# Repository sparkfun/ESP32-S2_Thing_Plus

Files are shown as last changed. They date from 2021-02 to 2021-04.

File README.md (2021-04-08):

SparkFun ESP32-S2 Thing Plus
========================================

SparkFun ESP32-S2 Thing Plus (https://www.sparkfun.com/products/17743)

[*SparkFun ESP32-S2 Thing Plus (WRL-17381)*](https://www.sparkfun.com/products/17743)

The [SparkFun ESP32-S2 Thing Plus](https://www.sparkfun.com/products/17743) is a comprehensive development platform for [Espressif's ESP32](https://espressif.com/en/products/hardware/esp32/overview). This board has the ESP32-S2-WROOM (4MB) version of the module. The new ESP32-S2 module addresses the [security flaws](https://www.espressif.com/en/news/ESP32_FIA_Analysis) in the original ESP32. While the ESP32-S2 does include improved security features, it lacks the Bluetooth capabilities of the original ESP32 module. The ESP32-S2 Thing Plus includes a Qwiic adapter, LiPo battery JST connector, and 21 I/O pins.

Repository Contents
-------------------

* **/Hardware** - Eagle design files (.brd, .sch)
* **/Hardware/Production** - Production panel files (gerbers, .brd)

Documentation
--------------
* **[Hookup Guide](https://learn.sparkfun.com/tutorials/1660)** - Basic hookup guide for the ESP32-S2 Thing Plus.
* **[SparkFun Graphical Datasheets](https://github.com/sparkfun/Graphical_Datasheets)** -Graphical Datasheets for various SparkFun products.

Product Versions
----------------
* [WRL-17743](https://www.sparkfun.com/products/17743)- v1.0, Initial Release

License Information
-------------------

This product is _**open source**_! 

Please review the LICENSE.md file for license information. 

If you have any questions or concerns on licensing, please contact technical support on our [SparkFun forums](https://forum.sparkfun.com/viewforum.php?f=152).

Distributed as-is; no warranty is given.

- Your friends at SparkFun.

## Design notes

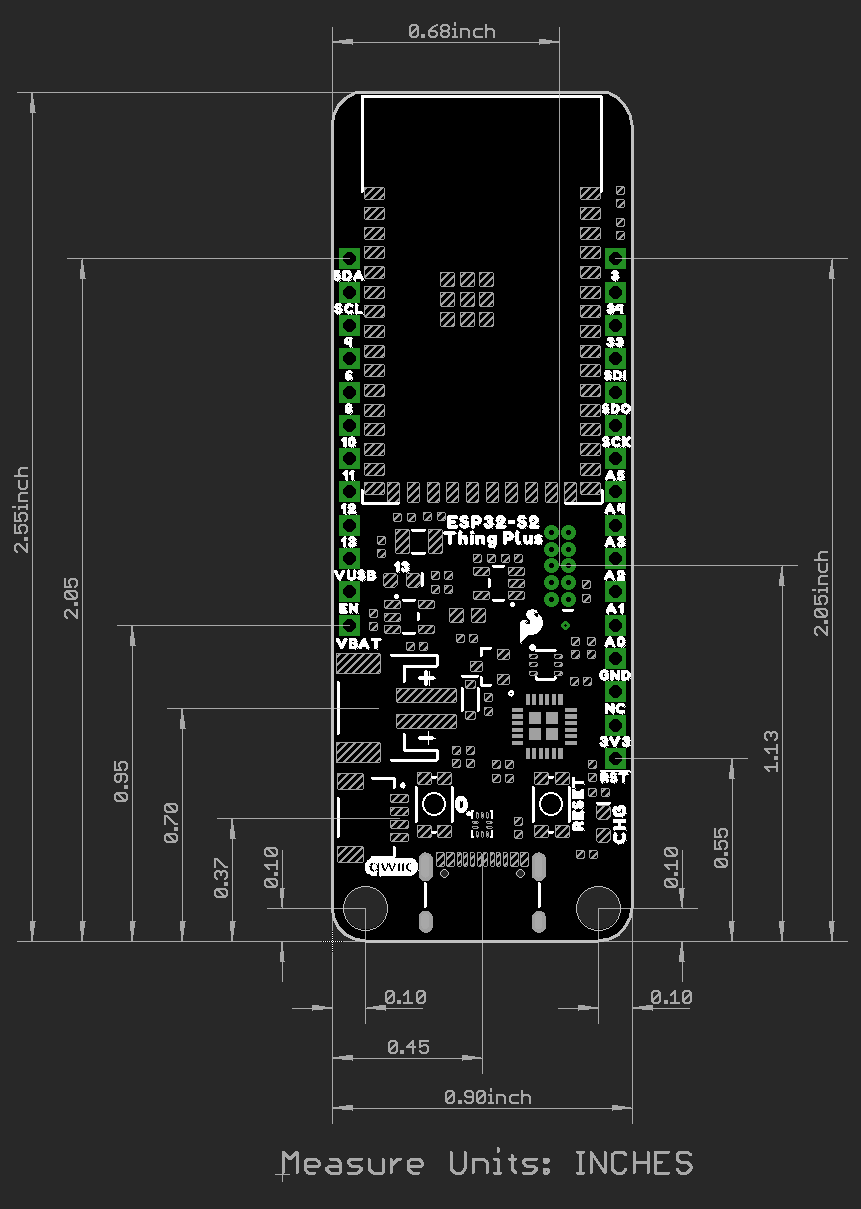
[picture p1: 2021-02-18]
Documents/ESP32-S2_Thing_Plus_DIMENSIONS.png

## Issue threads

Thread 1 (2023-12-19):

Feature Request: Battery charge status

santaimpersonator, 2023-12-19:
From customer feedback:

> There is only one thing I miss that I think you should consider changing for next iteration. A way to read charging status from the controller. To get this i soldered an aditional wire from the charging led to one of the pins. It does not even have to be there all the time, it could be a pad to solder closed and sacrifice a pin or something like this.

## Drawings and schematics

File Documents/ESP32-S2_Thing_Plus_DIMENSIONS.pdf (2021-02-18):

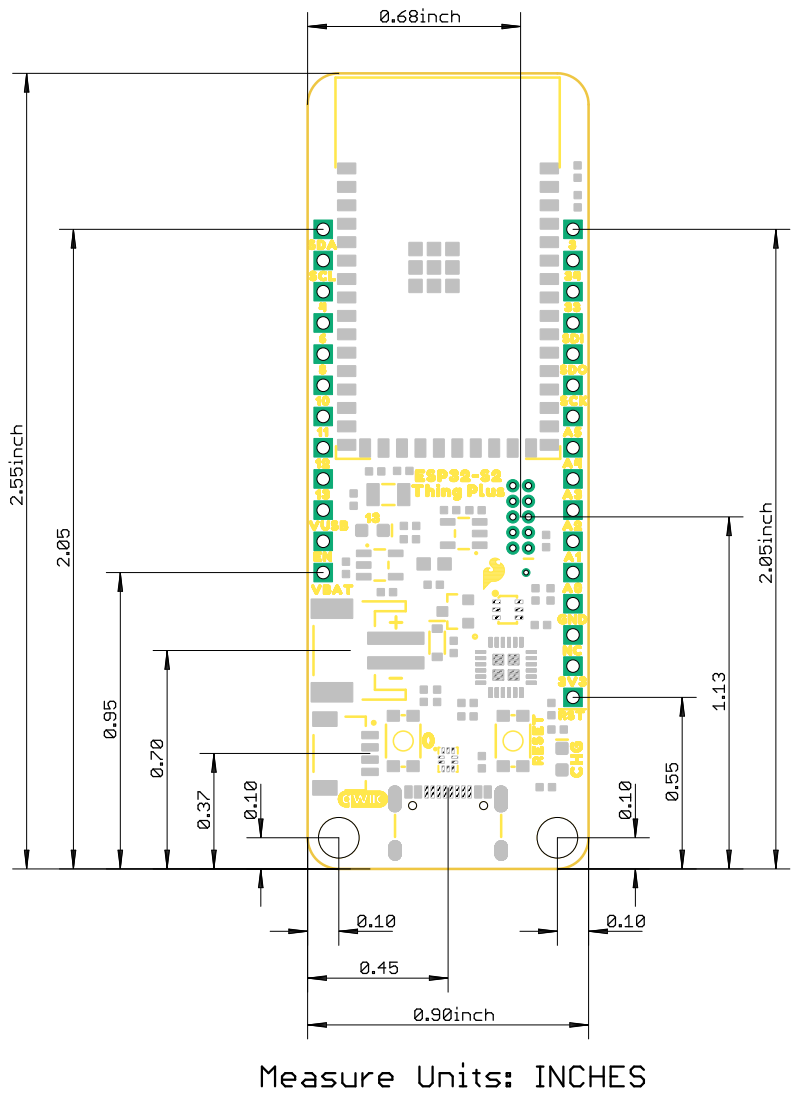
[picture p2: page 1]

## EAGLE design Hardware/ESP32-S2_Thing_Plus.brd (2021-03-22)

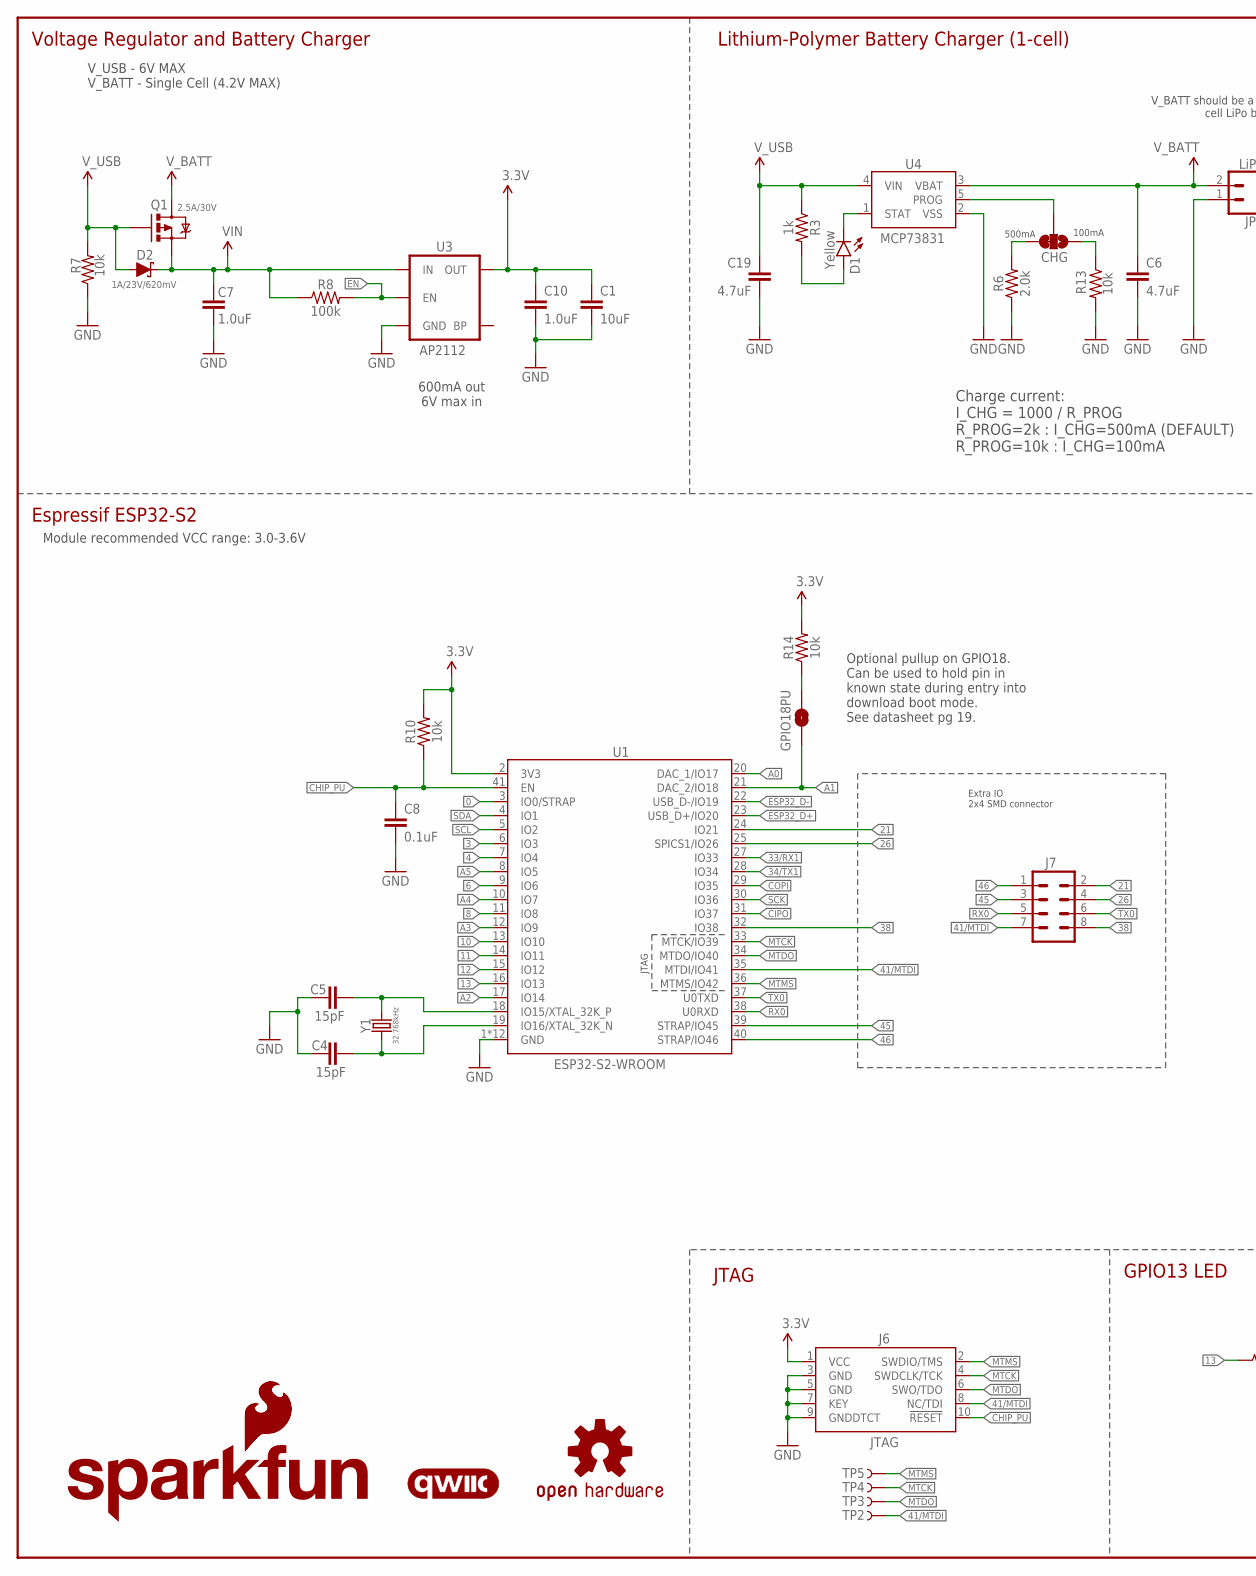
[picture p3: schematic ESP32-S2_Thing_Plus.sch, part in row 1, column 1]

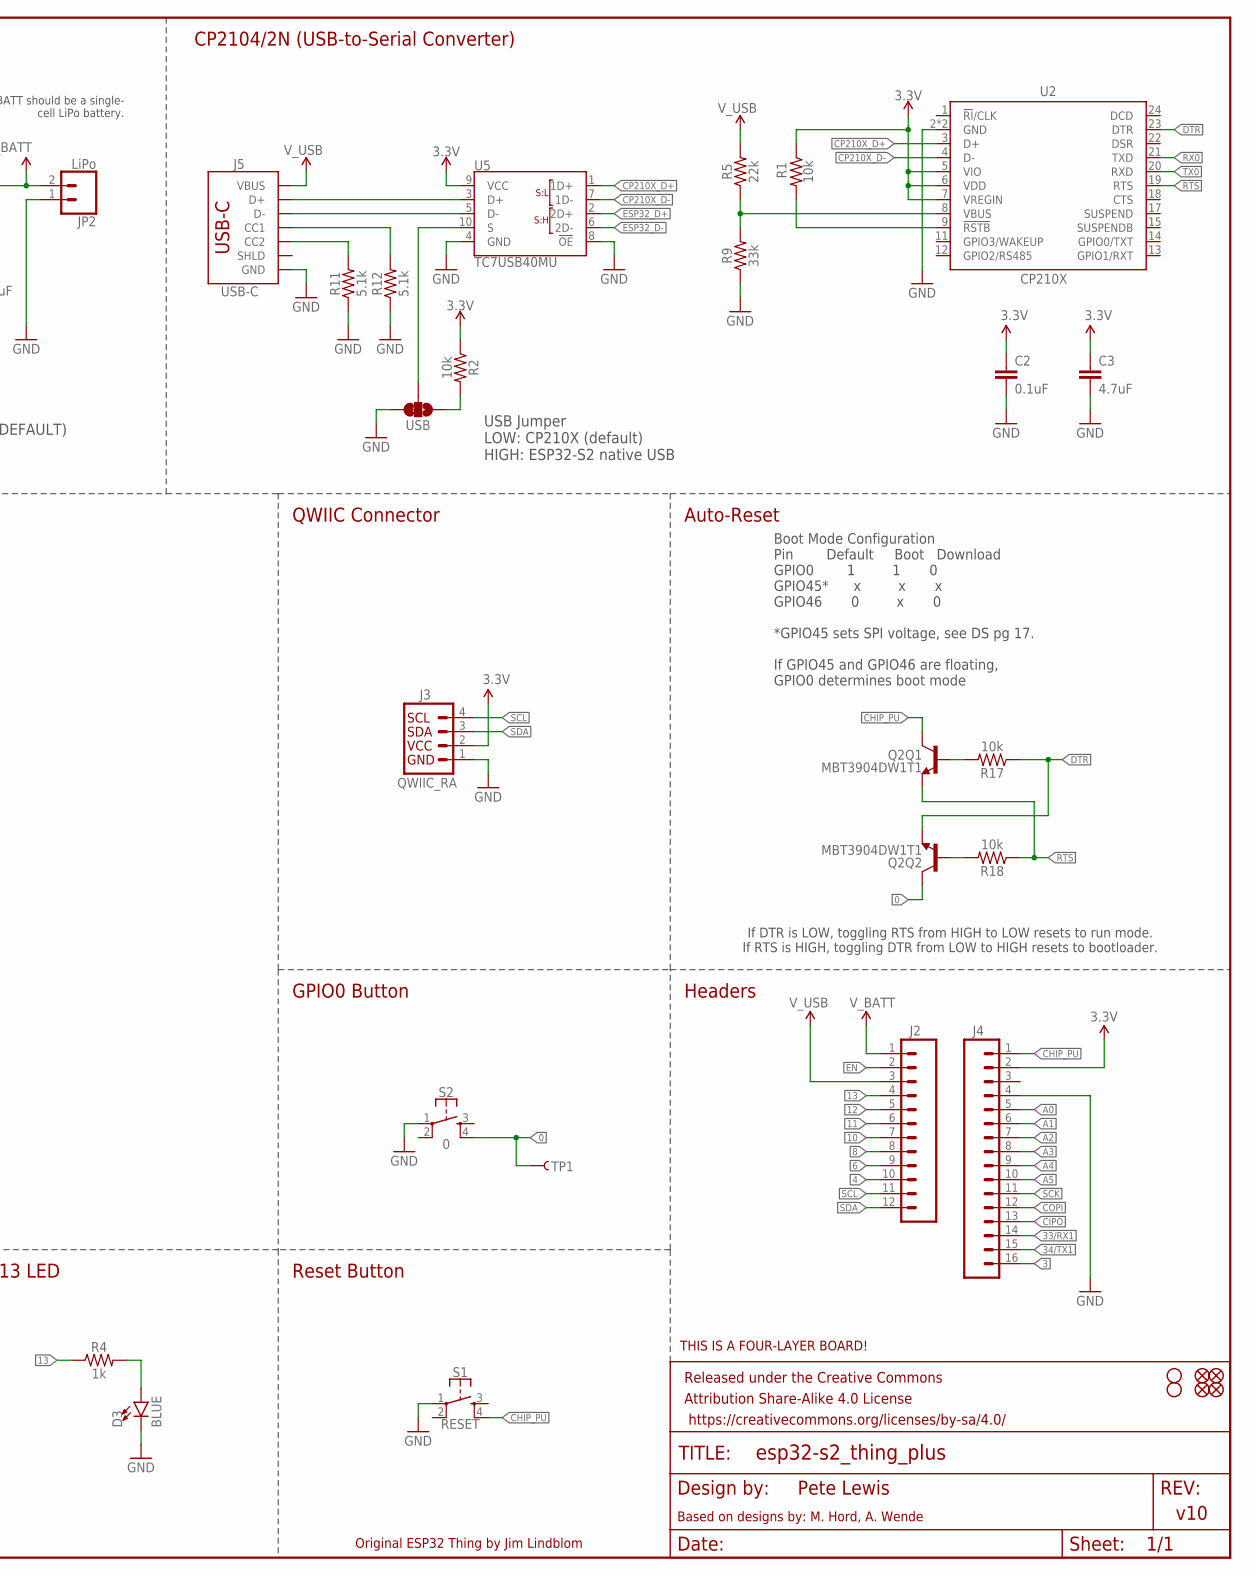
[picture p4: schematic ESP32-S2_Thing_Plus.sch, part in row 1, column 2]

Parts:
C1: 10uF; 0402-TIGHT
C2, C8: 0.1uF; 0402-TIGHT
C3, C6, C19: 4.7uF; 0402-TIGHT
C4, C5: 15pF; 0402-TIGHT
C7, C10: 1.0uF; 0402-TIGHT
CHG: JUMPER-SMT_3_1-NC_TRACE_SILK; SMT-JUMPER_3_1-NC_TRACE_SILK
D1: Yellow; LED-0603
D2: 1A/23V/620mV; SOD-323
D3: BLUE; LED-0603
FD1, FD2, FD3, FD4: FIDUCIALUFIDUCIAL; FIDUCIAL-MICRO
FRAME1: FRAME-LEDGER; CREATIVE_COMMONS
GPIO18PU: JUMPER-SMT_2_NO_SILK; SMT-JUMPER_2_NO_SILK
H1, H2: STAND-OFF
J2: CONN_12SM_SQ_NO_SILK; 1X12_SM_SQ_NOSILK
J3: QWIIC_RA; JST04_1MM_RA
J4: CONN_161X16_SM_SQ_NOSILK; 1X16_SM_SQ_NOSILK
J5: USB-C; USB-C-16P-4LAYER-ISOLATED
J6: JTAG; 2X5-PTH-1.27MM-NO_SILK
J7: CONN_04X2_SMT_NO_POSTS_NS; 2X4_SMT_NO_POSTS_NS
JP2: LiPo; JST-2-SMD
LOGO1: SFE_LOGO_FLAME.1_INCH; SFE_LOGO_FLAME_.1
LOGO2: OSHW-LOGOMINI; OSHW-LOGO-MINI
LOGO3: SFE_LOGO_NAME_FLAME.1_INCH; SFE_LOGO_NAME_FLAME_.1
LOGO4: FOUR_LAYER_WARNING
LOGO6: QWIIC_LOGO_4MM; QWIIC_4MM
Q1: 2.5A/30V; SOT23-3@1
Q2: MBT3904DW1T1; SC70-6
R1, R2, R7, R10, R13, R14, R17, R18: 10k; 0402-TIGHT
R3, R4: 1k; 0402-TIGHT
R5: 22k; 0402-TIGHT
R6: 2.0k; 0603
R8: 100k; 0402-TIGHT
R9: 33k; 0402-TIGHT
R11, R12: 5.1k; 0402-TIGHT
S1: RESET; TACTILE_SWITCH_SMD_4.6X2.8MM
S2: 0; TACTILE_SWITCH_SMD_4.6X2.8MM
TP1: TEST-POINTTP_15TH_THRU; TP_15TH
TP2, TP3, TP4, TP5: TEST-POINT3X4; PAD.03X.04
U1: ESP32-S2-WROOM
U2: CP210X; QFN24
U3: AP2112; SOT23-5
U4: MCP73831; SOT23-5
U5: TC7USB40MU; UQFN10
USB: JUMPER-SMT_3_1-NC_TRACE_SILK; SMT-JUMPER_3_1-NC_TRACE_SILK
Y1: 32.768kHz; CRYSTAL-SMD-3.2X1.5MM

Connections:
0: Q2.6 (C), S2.4, TP1.P$1, U1.3 (IO0/STRAP)
3: J4.16, U1.6 (IO3)
3.3V: C1.1, C2.1, C3.1, C10.1, J3.2, J4.2, J6.1 (VCC), R1.1, R2.1, R10.2, R14.2, U1.2 (3V3), U2.5 (VIO), U2.6 (VDD), U2.7 (VREGIN), U3.5 (OUT), U5.9 (VCC)
4: J2.10, U1.7 (IO4)
6: J2.9, U1.9 (IO6)
8: J2.8, U1.11 (IO8)
10: J2.7, U1.13 (IO10)
11: J2.6, U1.14 (IO11)
12: J2.5, U1.15 (IO12)
13: J2.4, R4.1, U1.16 (IO13)
21: J7.2, U1.24 (IO21)
26: J7.4, U1.25 (SPICS1/IO26)
33/RX1: J4.14, U1.27 (IO33)
34/TX1: J4.15, U1.28 (IO34)
38: J7.8, U1.32 (IO38)
41/MTDI: J6.8 (NC/TDI), J7.7, TP2.P$1, U1.35 (MTDI/IO41)
45: J7.3, U1.39 (STRAP/IO45)
46: J7.1, U1.40 (STRAP/IO46)
A0: J4.5, U1.20 (DAC_1/IO17)
A1: GPIO18PU.1, J4.6, U1.21 (DAC_2/IO18)
A2: J4.7, U1.17 (IO14)
A3: J4.8, U1.12 (IO9)
A4: J4.9, U1.10 (IO7)
A5: J4.10, U1.8 (IO5)
CC1: J5.A5 (CC1), R12.2
CC2: J5.B5 (CC2), R11.2
CHG: D1.C, U4.1 (STAT)
CHIP_PU: C8.1, J4.1, J6.10 (!RESET), Q2.3 (C), R10.1, S1.4, U1.41 (EN)
CIPO: J4.13, U1.31 (IO37)
COPI: J4.12, U1.29 (IO35)
CP210X_D+: U2.3 (D+), U5.1 (1D+)
CP210X_D-: U2.4 (D-), U5.7 (1D-)
DTR: Q2.1 (E), R17.1, U2.23 (DTR)
EN: J2.2, R8.2, U3.3 (EN)
ESP32_D+: U1.23 (USB_D+/IO20), U5.2 (2D+)
ESP32_D-: U1.22 (USB_D-/IO19), U5.6 (2D-)
GND: C1.2, C2.2, C3.2, C4.1, C5.1, C6.2, C7.2, C8.2, C10.2, C19.2, D3.C, J3.1, J4.4, J5.GND, J5.GND2 (GND), J6.3 (GND), J6.5 (GND), J6.7 (KEY), J6.9 (GNDDTCT), JP2.1 (2), R6.1, R7.1, R9.1, R11.1, R12.1, R13.2, S1.1, S2.1, U1.1 (GND), U1.26 (GND), U1.42 (GND), U1.GNDEP0 (GND), U1.GNDEP1 (GND), U1.GNDEP2 (GND), U1.GNDEP3 (GND), U1.GNDEP4 (GND), U1.GNDEP5 (GND), U1.GNDEP6 (GND), U1.GNDEP7 (GND), U1.GNDEP8 (GND), U2.2 (GND), U2.PAD (GND), U3.2 (GND), U4.2 (VSS), U5.4 (GND), U5.8 (!OE!), USB.3
MTCK: J6.4 (SWDCLK/TCK), TP4.P$1, U1.33 (MTCK/IO39)
MTDO: J6.6 (SWO/TDO), TP3.P$1, U1.34 (MTDO/IO40)
MTMS: J6.2 (SWDIO/TMS), TP5.P$1, U1.36 (MTMS/IO42)
unnamed: R1.2, U2.9 (!RSTB)
unnamed: D3.A, R4.2
unnamed: J5.A6 (D+), J5.B6 (D+), U5.3 (D+)
unnamed: R5.1, R9.2, U2.8 (VBUS)
unnamed: J5.A7 (D-), J5.B7 (D-), U5.5 (D-)
unnamed: R2.2, USB.1
unnamed: C5.2, U1.18 (IO15/XTAL_32K_P), Y1.P$2 (2)
unnamed: C4.2, U1.19 (IO16/XTAL_32K_N), Y1.P$1 (1)
unnamed: CHG.2, U4.5 (PROG)
unnamed: Q2.5 (B), R17.2
unnamed: CHG.1, R13.1
unnamed: Q2.2 (B), R18.2
unnamed: CHG.3, R6.2
unnamed: GPIO18PU.2, R14.1
unnamed: D1.A, R3.2
RTS: Q2.4 (E), R18.1, U2.19 (RTS)
RX0: J7.5, U1.38 (U0RXD), U2.21 (TXD)
SCK: J4.11, U1.30 (IO36)
SCL: J2.11, J3.4, U1.5 (IO2)
SDA: J2.12, J3.3, U1.4 (IO1)
TX0: J7.6, U1.37 (U0TXD), U2.20 (RXD)
USB_SEL: U5.10 (S), USB.2
VIN: C7.1, D2.C, Q1.2 (S), R8.1, U3.1 (IN)
V_BATT: C6.1, J2.1, JP2.2 (1), Q1.3 (D), U4.3 (VBAT)
V_USB: C19.1, D2.A, J2.3, J5.VBUS1 (VBUS), J5.VBUS2 (VBUS), Q1.1 (G), R3.1, R5.2, R7.2, U4.4 (VIN)

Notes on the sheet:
Boot Mode Configuration Pin Default Boot Download GPIO0 1 1 0 GPIO45* x x x GPIO46 0 x 0 *GPIO45 sets SPI voltage, see DS pg 17. If GPIO45 and GPIO46 are floating, GPIO0 determines boot mode
CP2104/2N (USB-to-Serial Converter)
V_BATT should be a single- cell LiPo battery.
Charge current: I_CHG = 1000 / R_PROG R_PROG=2k : I_CHG=500mA (DEFAULT) R_PROG=10k : I_CHG=100mA
Voltage Regulator and Battery Charger
Lithium-Polymer Battery Charger (1-cell)
600mA out 6V max in
Auto-Reset
Espressif ESP32-S2
Reset Button
Headers
v10
Original ESP32 Thing by Jim Lindblom
If DTR is LOW, toggling RTS from HIGH to LOW resets to run mode. If RTS is HIGH, toggling DTR from LOW to HIGH resets to bootloader.
QWIIC Connector
Pete Lewis
GPIO13 LED
GPIO0 Button
Based on designs by: M. Hord, A. Wende
V_USB - 6V MAX V_BATT - Single Cell (4.2V MAX)
100mA
500mA
Extra IO 2x4 SMD connector
JTAG
Module recommended VCC range: 3.0-3.6V
USB Jumper LOW: CP210X (default) HIGH: ESP32-S2 native USB
Optional pullup on GPIO18. Can be used to hold pin in known state during entry into download boot mode. See datasheet pg 19.

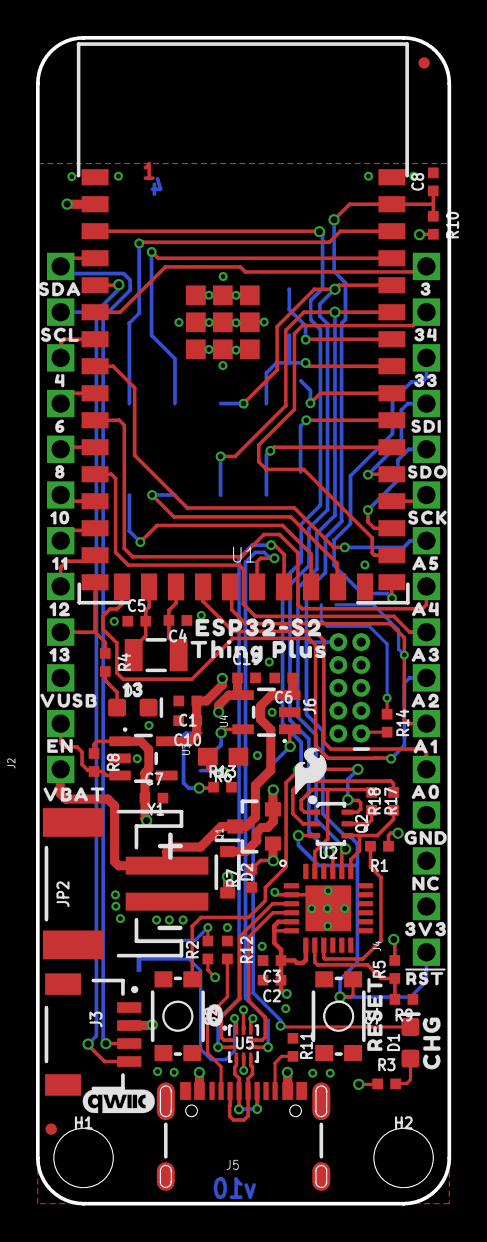
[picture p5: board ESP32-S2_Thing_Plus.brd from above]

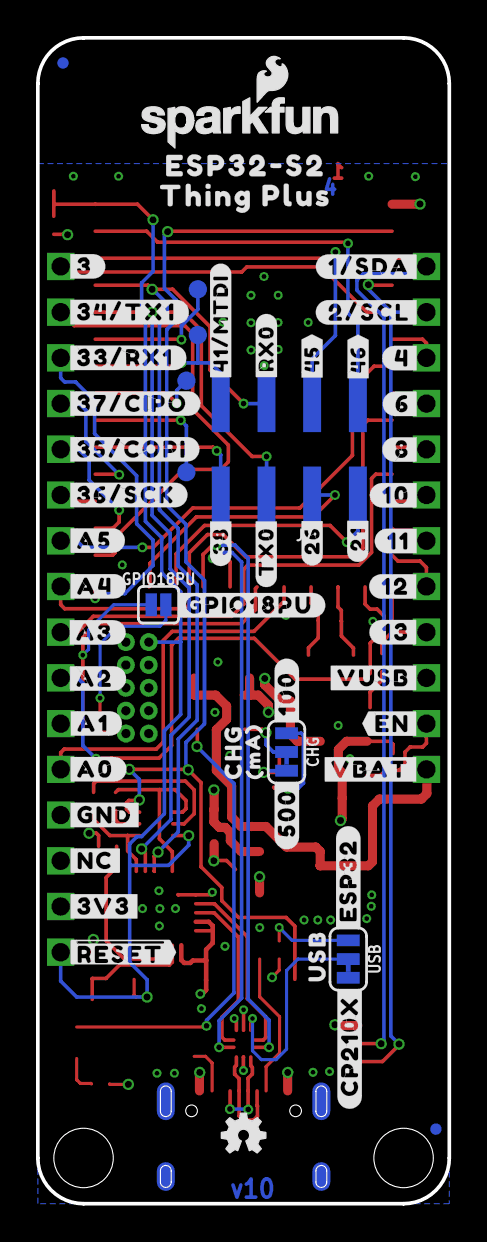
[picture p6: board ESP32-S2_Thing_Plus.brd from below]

Board: 4 copper layers, 22.9 x 64.8 mm, 147 parts (58 on the bottom side), 65 nets.

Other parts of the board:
U$1: #CP210X#0
U$2: SDI0
U$3, U$78: CHG0
U$4: #500#0
U$5: ESP32#S20
U$6: SDO0
U$7: #RST#0
U$8: #46#0
U$9: #ESP32#0
U$10: #45#0
U$11: MA0
U$12: #A5#0
U$14: USB0
U$15: 110
U$16: #GPIO18PU#0
U$17: 100
U$18: 80
U$19: #A4#0
U$20: 60
U$21: #A2#0
U$22: #A3#0
U$23: 40
U$24: 330
U$25: SDA0
U$26: SCL0
U$28: #A0#0
U$29: 340
U$30: 30
U$31: #36#SCK#0
U$32: #GND#0
U$33: #35#COPI#0
U$34: #37#CIPO#0
U$35: #33#RX1#0
U$36: #34#TX1#0
U$37: #3#0
U$38: #41#MTDI#0
U$39: #12#0
U$40: #13#0
U$41: #VUSB#0
U$42: #VBAT#0
U$43: #EN#0
U$44: #NC#0
U$45: #3V3#0
U$46: ##RESET##0
U$47: #11#0
U$48: #6#0
U$49: #8#0
U$50: #10#0
U$51: #4#0
U$52: #1#SDA#0
U$53: #2#SCL#0
U$54: #21#0
U$55: #26#0
U$56: #TX0#0
U$57: #38#0
U$58: #RX0#0
U$59: ORDERING_INSTRUCTIONS
U$60: #100#0
U$61: THING_PLUS0
U$62: THING_PLUS_0
U$63: ESP32#S2_0
U$64: #A1#0
U$72: 120
U$73, U$74: 130
U$75: VUSB0
U$76: EN0
U$77: VBAT0
U$79: RESET0
U$81: 3V30
U$82: NC0
U$83: GND0
U$84: A00
U$85: A10
U$86: A20
U$87: A30
U$88: A40
U$89: A50
U$90: SCK0
U$96: 00

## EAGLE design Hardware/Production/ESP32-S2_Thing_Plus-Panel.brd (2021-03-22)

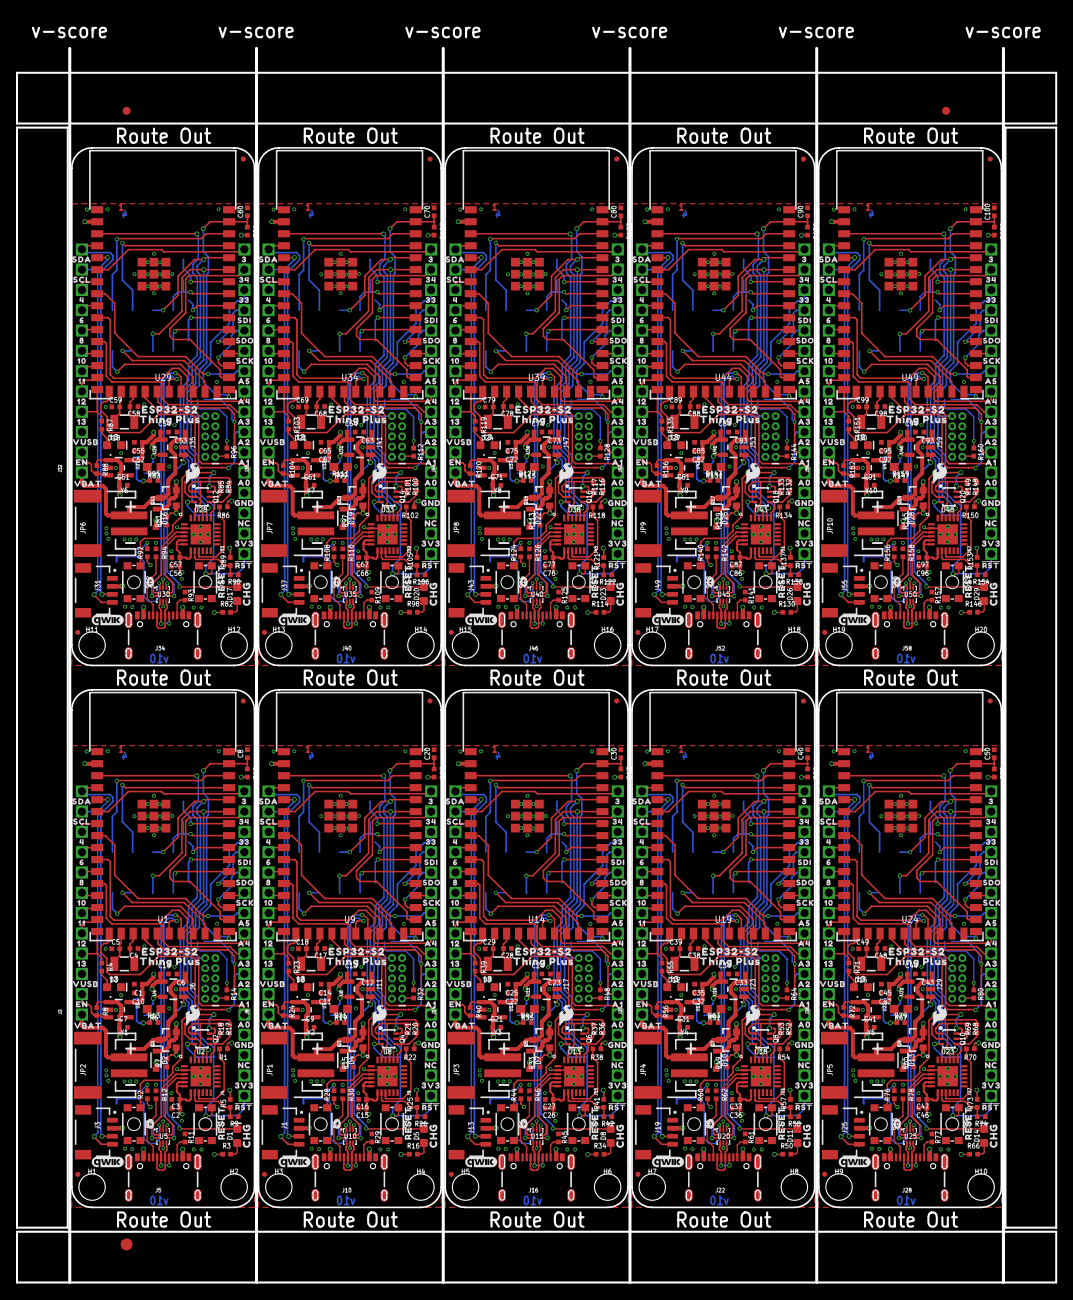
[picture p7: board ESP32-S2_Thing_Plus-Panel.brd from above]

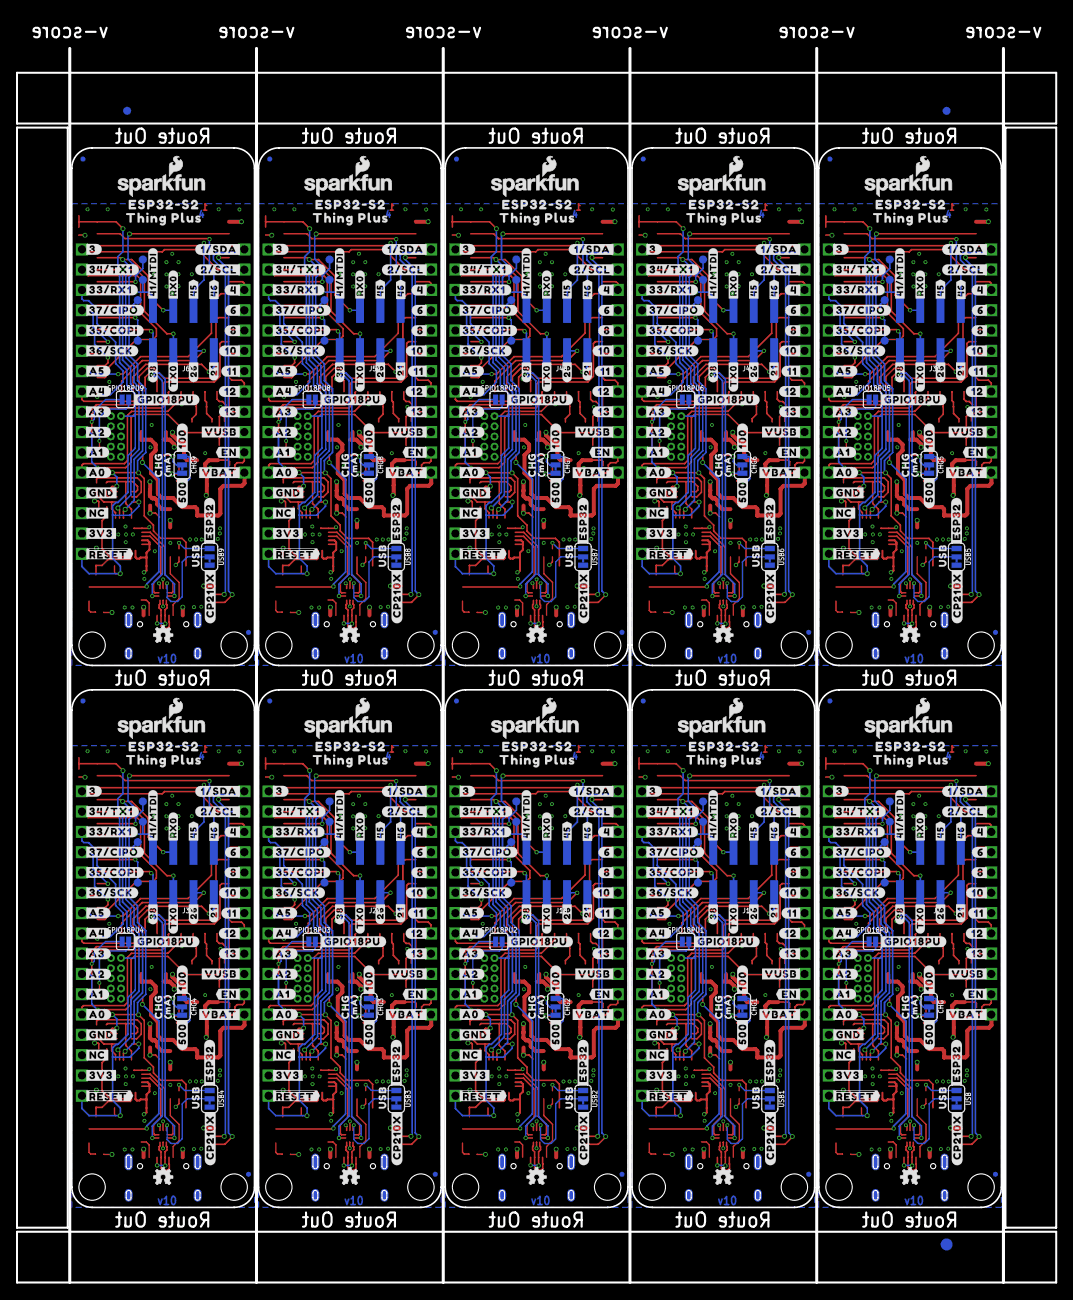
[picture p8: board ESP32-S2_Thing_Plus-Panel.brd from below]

Board: 4 copper layers, 130.0 x 154.4 mm, 1466 parts (583 on the bottom side), 650 nets.

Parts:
C1, C14, C25, C35, C45, C55, C65, C75, C85, C95: 10uF; 0402-TIGHT
C2, C8, C15, C20, C26, C30, C36, C40, C46, C50, C56, C60, C66, C70, C76, C80, C86, C90, C96, C100: 0.1uF; 0402-TIGHT
C3, C6, C12, C13, C16, C19, C23, C24, C27, C33, C34, C37, C43, C44, C47, C53, C54, C57, C63, C64, C67, C73, C74, C77, C83, C84, C87, C93, C94, C97: 4.7uF; 0402-TIGHT
C4, C5, C17, C18, C28, C29, C38, C39, C48, C49, C58, C59, C68, C69, C78, C79, C88, C89, C98, C99: 15pF; 0402-TIGHT
C7, C9, C10, C11, C21, C22, C31, C32, C41, C42, C51, C52, C61, C62, C71, C72, C81, C82, C91, C92: 1.0uF; 0402-TIGHT
CHG, CHG1, CHG2, CHG3, CHG4, CHG5, CHG6, CHG7, CHG8, CHG9: SMT-JUMPER_3_1-NC_TRACE_SILK
D1, D5, D8, D11, D14, D17, D20, D23, D26, D29: Yellow; LED-0603
D2, D4, D7, D10, D13, D16, D19, D22, D25, D28: 1A/23V/620mV; SOD-323
D3, D6, D9, D12, D15, D18, D21, D24, D27, D30: BLUE; LED-0603
E$1, E$2, E$3, E$4: FIDUCIAL-1X2
E$5, E$6: FIDUCIAL-1.5X3
FD1, FD2, FD3, FD4, FD5, FD6, FD7, FD8, FD9, FD10, FD11, FD12, FD13, FD14, FD15, FD16, FD17, FD18, FD19, FD20, FD21, FD22, FD23, FD24, FD25, FD26, FD27, FD28, FD29, FD30, FD31, FD32, FD33, FD34, FD35, FD36, FD37, FD38, FD39, FD40: FIDUCIALUFIDUCIAL; FIDUCIAL-MICRO
GPIO18PU, GPIO18PU1, GPIO18PU2, GPIO18PU3, GPIO18PU4, GPIO18PU5, GPIO18PU6, GPIO18PU7, GPIO18PU8, GPIO18PU9: SMT-JUMPER_2_NO_SILK
H1, H2, H3, H4, H5, H6, H7, H8, H9, H10, H11, H12, H13, H14, H15, H16, H17, H18, H19, H20: STAND-OFF
J1, J3, J13, J19, J25, J31, J37, J43, J49, J55: QWIIC_RA; JST04_1MM_RA
J2, J8, J14, J20, J26, J32, J38, J44, J50, J56: 1X12_SM_SQ_NOSILK
J4, J9, J15, J21, J27, J33, J39, J45, J51, J57: 1X16_SM_SQ_NOSILK
J5, J10, J16, J22, J28, J34, J40, J46, J52, J58: USB-C; USB-C-16P-4LAYER-ISOLATED
J6, J11, J17, J23, J29, J35, J41, J47, J53, J59: JTAG; 2X5-PTH-1.27MM-NO_SILK
J7, J12, J18, J24, J30, J36, J42, J48, J54, J60: 2X4_SMT_NO_POSTS_NS
JP1, JP2, JP3, JP4, JP5, JP6, JP7, JP8, JP9, JP10: LiPo; JST-2-SMD
LOGO1, LOGO10, LOGO15, LOGO20, LOGO25, LOGO30, LOGO35, LOGO40, LOGO45, LOGO50: SFE_LOGO_FLAME.1_INCH; SFE_LOGO_FLAME_.1
LOGO2, LOGO5, LOGO11, LOGO16, LOGO21, LOGO26, LOGO31, LOGO36, LOGO41, LOGO46: OSHW-LOGOMINI; OSHW-LOGO-MINI
LOGO3, LOGO7, LOGO12, LOGO17, LOGO22, LOGO27, LOGO32, LOGO37, LOGO42, LOGO47: SFE_LOGO_NAME_FLAME.1_INCH; SFE_LOGO_NAME_FLAME_.1
LOGO4, LOGO8, LOGO13, LOGO18, LOGO23, LOGO28, LOGO33, LOGO38, LOGO43, LOGO48: FOUR_LAYER_WARNING
LOGO6, LOGO9, LOGO14, LOGO19, LOGO24, LOGO29, LOGO34, LOGO39, LOGO44, LOGO49: QWIIC_LOGO_4MM; QWIIC_4MM
Q1, Q3, Q5, Q7, Q9, Q11, Q13, Q15, Q17, Q19: 2.5A/30V; SOT23-3@1
Q2, Q4, Q6, Q8, Q10, Q12, Q14, Q16, Q18, Q20: MBT3904DW1T1; SC70-6
R1, R2, R7, R10, R13, R14, R15, R17, R18, R20, R21, R22, R27, R28, R31, R32, R33, R36, R37, R38, R43, R44, R47, R48, R49, R52, R53, R54, R59, R60, R63, R64, R65, R68, R69, R70, R75, R76, R79, R80, R81, R84, R85, R86, R91, R92, R95, R96, R97, R100, R101, R102, R107, R108, R111, R112, R113, R116, R117, R118, R123, R124, R127, R128, R129, R132, R133, R134, R139, R140, R143, R144, R145, R148, R149, R150, R155, R156, R159, R160: 10k; 0402-TIGHT
R3, R4, R16, R23, R34, R39, R50, R55, R66, R71, R82, R87, R98, R103, R114, R119, R130, R135, R146, R151: 1k; 0402-TIGHT
R5, R25, R41, R57, R73, R89, R105, R121, R137, R153: 22k; 0402-TIGHT
R6, R19, R35, R51, R67, R83, R99, R115, R131, R147: 2.0k; 0603
R8, R24, R40, R56, R72, R88, R104, R120, R136, R152: 100k; 0402-TIGHT
R9, R26, R42, R58, R74, R90, R106, R122, R138, R154: 33k; 0402-TIGHT
R11, R12, R29, R30, R45, R46, R61, R62, R77, R78, R93, R94, R109, R110, R125, R126, R141, R142, R157, R158: 5.1k; 0402-TIGHT
S1, S3, S5, S7, S9, S11, S13, S15, S17, S19: RESET; TACTILE_SWITCH_SMD_4.6X2.8MM
S2, S4, S6, S8, S10, S12, S14, S16, S18, S20: 0; TACTILE_SWITCH_SMD_4.6X2.8MM
TP1, TP6, TP11, TP16, TP21, TP26, TP31, TP36, TP41, TP46: TP_15TH
TP2, TP3, TP4, TP5, TP7, TP8, TP9, TP10, TP12, TP13, TP14, TP15, TP17, TP18, TP19, TP20, TP22, TP23, TP24, TP25, TP27, TP28, TP29, TP30, TP32, TP33, TP34, TP35, TP37, TP38, TP39, TP40, TP42, TP43, TP44, TP45, TP47, TP48, TP49, TP50: PAD.03X.04
U1, U9, U14, U19, U24, U29, U34, U39, U44, U49: ESP32-S2-WROOM
U2, U8, U13, U18, U23, U28, U33, U38, U43, U48: CP210X; QFN24
U3, U7, U12, U17, U22, U27, U32, U37, U42, U47: AP2112; SOT23-5
U4, U6, U11, U16, U21, U26, U31, U36, U41, U46: MCP73831; SOT23-5
U5, U10, U15, U20, U25, U30, U35, U40, U45, U50: TC7USB40MU; UQFN10
U$1, U$160, U$241, U$322, U$403, U$484, U$565, U$646, U$727, U$808: #CP210X#0
U$2, U$116, U$197, U$278, U$359, U$440, U$521, U$602, U$683, U$764: SDI0
U$3, U$78, U$80, U$141, U$172, U$222, U$253, U$303, U$334, U$384, U$415, U$465, U$496, U$546, U$577, U$627, U$658, U$708, U$739, U$789: CHG0
U$4, U$152, U$233, U$314, U$395, U$476, U$557, U$638, U$719, U$800: #500#0
U$5, U$153, U$234, U$315, U$396, U$477, U$558, U$639, U$720, U$801: ESP32#S20
U$6, U$117, U$198, U$279, U$360, U$441, U$522, U$603, U$684, U$765: SDO0
U$7, U$118, U$199, U$280, U$361, U$442, U$523, U$604, U$685, U$766: #RST#0
U$8, U$142, U$223, U$304, U$385, U$466, U$547, U$628, U$709, U$790: #46#0
U$9, U$161, U$242, U$323, U$404, U$485, U$566, U$647, U$728, U$809: #ESP32#0
U$10, U$143, U$224, U$305, U$386, U$467, U$548, U$629, U$710, U$791: #45#0
U$11, U$150, U$231, U$312, U$393, U$474, U$555, U$636, U$717, U$798: MA0
U$12, U$109, U$190, U$271, U$352, U$433, U$514, U$595, U$676, U$757: #A5#0
U$13, U$59, U$163, U$244, U$325, U$406, U$487, U$568, U$649, U$730: ORDERING_INSTRUCTIONS
U$14, U$119, U$200, U$281, U$362, U$443, U$524, U$605, U$686, U$767: USB0
U$15, U$120, U$201, U$282, U$363, U$444, U$525, U$606, U$687, U$768: 110
U$16, U$162, U$243, U$324, U$405, U$486, U$567, U$648, U$729, U$810: #GPIO18PU#0
U$17, U$121, U$202, U$283, U$364, U$445, U$526, U$607, U$688, U$769: 100
U$18, U$122, U$203, U$284, U$365, U$446, U$527, U$608, U$689, U$770: 80
U$19, U$110, U$191, U$272, U$353, U$434, U$515, U$596, U$677, U$758: #A4#0
U$20, U$123, U$204, U$285, U$366, U$447, U$528, U$609, U$690, U$771: 60
U$21, U$158, U$239, U$320, U$401, U$482, U$563, U$644, U$725, U$806: #A2#0
U$22, U$159, U$240, U$321, U$402, U$483, U$564, U$645, U$726, U$807: #A3#0
U$23, U$124, U$205, U$286, U$367, U$448, U$529, U$610, U$691, U$772: 40
U$24, U$125, U$206, U$287, U$368, U$449, U$530, U$611, U$692, U$773: 330
U$25, U$27, U$164, U$245, U$326, U$407, U$488, U$569, U$650, U$731: SDA0
U$26, U$65, U$165, U$246, U$327, U$408, U$489, U$570, U$651, U$732: SCL0
U$28, U$111, U$192, U$273, U$354, U$435, U$516, U$597, U$678, U$759: #A0#0
U$29, U$126, U$207, U$288, U$369, U$450, U$531, U$612, U$693, U$774: 340
U$30, U$127, U$208, U$289, U$370, U$451, U$532, U$613, U$694, U$775: 30
U$31, U$135, U$216, U$297, U$378, U$459, U$540, U$621, U$702, U$783: #36#SCK#0
U$32, U$112, U$193, U$274, U$355, U$436, U$517, U$598, U$679, U$760: #GND#0
U$33, U$136, U$217, U$298, U$379, U$460, U$541, U$622, U$703, U$784: #35#COPI#0
U$34, U$137, U$218, U$299, U$380, U$461, U$542, U$623, U$704, U$785: #37#CIPO#0
U$35, U$138, U$219, U$300, U$381, U$462, U$543, U$624, U$705, U$786: #33#RX1#0
U$36, U$139, U$220, U$301, U$382, U$463, U$544, U$625, U$706, U$787: #34#TX1#0
U$37, U$140, U$221, U$302, U$383, U$464, U$545, U$626, U$707, U$788: #3#0
U$38, U$144, U$225, U$306, U$387, U$468, U$549, U$630, U$711, U$792: #41#MTDI#0
U$39, U$104, U$185, U$266, U$347, U$428, U$509, U$590, U$671, U$752: #12#0
U$40, U$105, U$186, U$267, U$348, U$429, U$510, U$591, U$672, U$753: #13#0
U$41, U$106, U$187, U$268, U$349, U$430, U$511, U$592, U$673, U$754: #VUSB#0
U$42, U$107, U$188, U$269, U$350, U$431, U$512, U$593, U$674, U$755: #VBAT#0
U$43, U$108, U$189, U$270, U$351, U$432, U$513, U$594, U$675, U$756: #EN#0
U$44, U$113, U$194, U$275, U$356, U$437, U$518, U$599, U$680, U$761: #NC#0
U$45, U$114, U$195, U$276, U$357, U$438, U$519, U$600, U$681, U$762: #3V3#0
U$46, U$115, U$196, U$277, U$358, U$439, U$520, U$601, U$682, U$763: ##RESET##0
U$47, U$128, U$209, U$290, U$371, U$452, U$533, U$614, U$695, U$776: #11#0
U$48, U$131, U$212, U$293, U$374, U$455, U$536, U$617, U$698, U$779: #6#0
U$49, U$129, U$210, U$291, U$372, U$453, U$534, U$615, U$696, U$777: #8#0
U$50, U$130, U$211, U$292, U$373, U$454, U$535, U$616, U$697, U$778: #10#0
U$51, U$132, U$213, U$294, U$375, U$456, U$537, U$618, U$699, U$780: #4#0
U$52, U$133, U$214, U$295, U$376, U$457, U$538, U$619, U$700, U$781: #1#SDA#0
U$53, U$134, U$215, U$296, U$377, U$458, U$539, U$620, U$701, U$782: #2#SCL#0
U$54, U$145, U$226, U$307, U$388, U$469, U$550, U$631, U$712, U$793: #21#0
U$55, U$146, U$227, U$308, U$389, U$470, U$551, U$632, U$713, U$794: #26#0
U$56, U$147, U$228, U$309, U$390, U$471, U$552, U$633, U$714, U$795: #TX0#0
U$57, U$148, U$229, U$310, U$391, U$472, U$553, U$634, U$715, U$796: #38#0
U$58, U$149, U$230, U$311, U$392, U$473, U$554, U$635, U$716, U$797: #RX0#0
U$60, U$151, U$232, U$313, U$394, U$475, U$556, U$637, U$718, U$799: #100#0
U$61, U$154, U$235, U$316, U$397, U$478, U$559, U$640, U$721, U$802: THING_PLUS0
U$62, U$155, U$236, U$317, U$398, U$479, U$560, U$641, U$722, U$803: THING_PLUS_0
U$63, U$156, U$237, U$318, U$399, U$480, U$561, U$642, U$723, U$804: ESP32#S2_0
U$64, U$157, U$238, U$319, U$400, U$481, U$562, U$643, U$724, U$805: #A1#0
U$66, U$72, U$166, U$247, U$328, U$409, U$490, U$571, U$652, U$733: 120
U$67, U$68, U$73, U$74, U$167, U$168, U$248, U$249, U$329, U$330, U$410, U$411, U$491, U$492, U$572, U$573, U$653, U$654, U$734, U$735: 130
U$69, U$75, U$169, U$250, U$331, U$412, U$493, U$574, U$655, U$736: VUSB0
U$70, U$76, U$170, U$251, U$332, U$413, U$494, U$575, U$656, U$737: EN0
U$71, U$77, U$171, U$252, U$333, U$414, U$495, U$576, U$657, U$738: VBAT0
U$79, U$91, U$173, U$254, U$335, U$416, U$497, U$578, U$659, U$740: RESET0
U$81, U$92, U$174, U$255, U$336, U$417, U$498, U$579, U$660, U$741: 3V30
U$82, U$93, U$175, U$256, U$337, U$418, U$499, U$580, U$661, U$742: NC0
U$83, U$94, U$176, U$257, U$338, U$419, U$500, U$581, U$662, U$743: GND0
U$84, U$95, U$177, U$258, U$339, U$420, U$501, U$582, U$663, U$744: A00
U$85, U$97, U$178, U$259, U$340, U$421, U$502, U$583, U$664, U$745: A10
U$86, U$98, U$179, U$260, U$341, U$422, U$503, U$584, U$665, U$746: A20
U$87, U$99, U$180, U$261, U$342, U$423, U$504, U$585, U$666, U$747: A30
U$88, U$100, U$181, U$262, U$343, U$424, U$505, U$586, U$667, U$748: A40
U$89, U$101, U$182, U$263, U$344, U$425, U$506, U$587, U$668, U$749: A50
U$90, U$102, U$183, U$264, U$345, U$426, U$507, U$588, U$669, U$750: SCK0
U$96, U$103, U$184, U$265, U$346, U$427, U$508, U$589, U$670, U$751: 00
USB, USB1, USB2, USB3, USB4, USB5, USB6, USB7, USB8, USB9: SMT-JUMPER_3_1-NC_TRACE_SILK
Y1, Y2, Y3, Y4, Y5, Y6, Y7, Y8, Y9, Y10: 32.768kHz; CRYSTAL-SMD-3.2X1.5MM

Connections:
0: Q2.6, S2.4, TP1.P$1, U1.3
1: Q4.6, S4.4, TP6.P$1, U9.3
2: J8.4, R23.1, U9.16
3: J4.16, U1.6
3.3V: C1.1, C2.1, C3.1, C10.1, J3.2, J4.2, J6.1, R1.1, R2.1, R10.2, R14.2, U1.2, U2.5, U2.6, U2.7, U3.5, U5.9
3.3V1: C11.1, C14.1, C15.1, C16.1, J1.2, J9.2, J11.1, R22.1, R27.2, R28.1, R32.2, U7.5, U8.5, U8.6, U8.7, U9.2, U10.9
3.3V2: C22.1, C25.1, C26.1, C27.1, J13.2, J15.2, J17.1, R38.1, R43.2, R44.1, R48.2, U12.5, U13.5, U13.6, U13.7, U14.2, U15.9
3.3V3: C32.1, C35.1, C36.1, C37.1, J19.2, J21.2, J23.1, R54.1, R59.2, R60.1, R64.2, U17.5, U18.5, U18.6, U18.7, U19.2, U20.9
3.3V4: C42.1, C45.1, C46.1, C47.1, J25.2, J27.2, J29.1, R70.1, R75.2, R76.1, R80.2, U22.5, U23.5, U23.6, U23.7, U24.2, U25.9
3.3V5: C52.1, C55.1, C56.1, C57.1, J31.2, J33.2, J35.1, R86.1, R91.2, R92.1, R96.2, U27.5, U28.5, U28.6, U28.7, U29.2, U30.9
3.3V6: C62.1, C65.1, C66.1, C67.1, J37.2, J39.2, J41.1, R102.1, R107.2, R108.1, R112.2, U32.5, U33.5, U33.6, U33.7, U34.2, U35.9
3.3V7: C72.1, C75.1, C76.1, C77.1, J43.2, J45.2, J47.1, R118.1, R123.2, R124.1, R128.2, U37.5, U38.5, U38.6, U38.7, U39.2, U40.9
3.3V8: C82.1, C85.1, C86.1, C87.1, J49.2, J51.2, J53.1, R134.1, R139.2, R140.1, R144.2, U42.5, U43.5, U43.6, U43.7, U44.2, U45.9
3.3V9: C92.1, C95.1, C96.1, C97.1, J55.2, J57.2, J59.1, R150.1, R155.2, R156.1, R160.2, U47.5, U48.5, U48.6, U48.7, U49.2, U50.9
4: J2.10, U1.7
5: J8.5, U9.15
6: J2.9, U1.9
7: J8.6, U9.14
8: J2.8, U1.11
9: J8.7, U9.13
10: J2.7, U1.13
11: J2.6, U1.14
12: J2.5, U1.15
13: J2.4, R4.1, U1.16
14: J8.8, U9.11
15: J8.9, U9.9
16: J8.10, U9.7
17: J9.16, U9.6
18: J12.3, U9.39
19: J12.1, U9.40
20: J12.8, U9.32
21: J7.2, U1.24
22: J12.2, U9.24
23: J12.4, U9.25
24: Q6.6, S6.4, TP11.P$1, U14.3
25: J14.4, R39.1, U14.16
26: J7.4, U1.25
27: J14.5, U14.15
28: J14.6, U14.14
29: J14.7, U14.13
30: J14.8, U14.11
31: J14.9, U14.9
32: J14.10, U14.7
33: J15.16, U14.6
33/RX1: J4.14, U1.27
33/RX2: J9.14, U9.27
33/RX3: J15.14, U14.27
33/RX4: J21.14, U19.27
33/RX5: J27.14, U24.27
33/RX6: J33.14, U29.27
33/RX7: J39.14, U34.27
33/RX8: J45.14, U39.27
33/RX9: J51.14, U44.27
33/RX10: J57.14, U49.27
34: J18.3, U14.39
34/TX1: J4.15, U1.28
34/TX2: J9.15, U9.28
34/TX3: J15.15, U14.28
34/TX4: J21.15, U19.28
34/TX5: J27.15, U24.28
34/TX6: J33.15, U29.28
34/TX7: J39.15, U34.28
34/TX8: J45.15, U39.28
34/TX9: J51.15, U44.28
34/TX10: J57.15, U49.28
35: J18.1, U14.40
36: J18.8, U14.32
37: J18.2, U14.24
38: J7.8, U1.32
39: J18.4, U14.25
40: Q8.6, S8.4, TP16.P$1, U19.3
41: J20.4, R55.1, U19.16
41/MTDI: J6.8, J7.7, TP2.P$1, U1.35
41/MTDI1: J11.8, J12.7, TP10.P$1, U9.35
41/MTDI2: J17.8, J18.7, TP15.P$1, U14.35
41/MTDI3: J23.8, J24.7, TP20.P$1, U19.35
41/MTDI4: J29.8, J30.7, TP25.P$1, U24.35
41/MTDI5: J35.8, J36.7, TP30.P$1, U29.35
41/MTDI6: J41.8, J42.7, TP35.P$1, U34.35
41/MTDI7: J47.8, J48.7, TP40.P$1, U39.35
41/MTDI8: J53.8, J54.7, TP45.P$1, U44.35
41/MTDI9: J59.8, J60.7, TP50.P$1, U49.35
42: J20.5, U19.15
43: J20.6, U19.14
44: J20.7, U19.13
45: J7.3, U1.39
46: J7.1, U1.40
47: J20.8, U19.11
48: J20.9, U19.9
49: J20.10, U19.7
50: J21.16, U19.6
51: J24.3, U19.39
52: J24.1, U19.40
53: J24.8, U19.32
54: J24.2, U19.24
55: J24.4, U19.25
56: Q10.6, S10.4, TP21.P$1, U24.3
57: J26.4, R71.1, U24.16
58: J26.5, U24.15
59: J26.6, U24.14
60: J26.7, U24.13
61: J26.8, U24.11
62: J26.9, U24.9
63: J26.10, U24.7
64: J27.16, U24.6
65: J30.3, U24.39
66: J30.1, U24.40
67: J30.8, U24.32
68: J30.2, U24.24
69: J30.4, U24.25
70: Q12.6, S12.4, TP26.P$1, U29.3
71: J32.4, R87.1, U29.16
72: J32.5, U29.15
73: J32.6, U29.14
74: J32.7, U29.13
75: J32.8, U29.11
76: J32.9, U29.9
77: J32.10, U29.7
78: J33.16, U29.6
79: J36.3, U29.39
80: J36.1, U29.40
81: J36.8, U29.32
82: J36.2, U29.24
83: J36.4, U29.25
84: Q14.6, S14.4, TP31.P$1, U34.3
85: J38.4, R103.1, U34.16
86: J38.5, U34.15
87: J38.6, U34.14
88: J38.7, U34.13
89: J38.8, U34.11
90: J38.9, U34.9
91: J38.10, U34.7
92: J39.16, U34.6
93: J42.3, U34.39
94: J42.1, U34.40
95: J42.8, U34.32
96: J42.2, U34.24
97: J42.4, U34.25
98: Q16.6, S16.4, TP36.P$1, U39.3
99: J44.4, R119.1, U39.16
100: J44.5, U39.15
101: J44.6, U39.14
102: J44.7, U39.13
103: J44.8, U39.11
104: J44.9, U39.9
105: J44.10, U39.7
106: J45.16, U39.6
107: J48.3, U39.39
108: J48.1, U39.40
109: J48.8, U39.32
110: J48.2, U39.24
111: J48.4, U39.25
112: Q18.6, S18.4, TP41.P$1, U44.3
113: J50.4, R135.1, U44.16
114: J50.5, U44.15
115: J50.6, U44.14
116: J50.7, U44.13
117: J50.8, U44.11
118: J50.9, U44.9
119: J50.10, U44.7
120: J51.16, U44.6
121: J54.3, U44.39
122: J54.1, U44.40
123: J54.8, U44.32
124: J54.2, U44.24
125: J54.4, U44.25
126: Q20.6, S20.4, TP46.P$1, U49.3
127: J56.4, R151.1, U49.16
128: J56.5, U49.15
129: J56.6, U49.14
130: J56.7, U49.13
131: J56.8, U49.11
132: J56.9, U49.9
133: J56.10, U49.7
134: J57.16, U49.6
135: J60.3, U49.39
136: J60.1, U49.40
137: J60.8, U49.32
138: J60.2, U49.24
139: J60.4, U49.25
A0: J4.5, U1.20
A1: GPIO18PU.1, J4.6, U1.21
A2: J4.7, U1.17
A3: J4.8, U1.12
A4: J4.9, U1.10
A5: J4.10, U1.8
A6: J9.5, U9.20
A7: GPIO18PU1.1, J9.6, U9.21
A8: J9.7, U9.17
A9: J9.8, U9.12
A10: J9.9, U9.10
A11: J9.10, U9.8
A12: J15.5, U14.20
A13: GPIO18PU2.1, J15.6, U14.21
A14: J15.7, U14.17
A15: J15.8, U14.12
A16: J15.9, U14.10
A17: J15.10, U14.8
A18: J21.5, U19.20
A19: GPIO18PU3.1, J21.6, U19.21
A20: J21.7, U19.17
A21: J21.8, U19.12
A22: J21.9, U19.10
A23: J21.10, U19.8
A24: J27.5, U24.20
A25: GPIO18PU4.1, J27.6, U24.21
A26: J27.7, U24.17
A27: J27.8, U24.12
A28: J27.9, U24.10
A29: J27.10, U24.8
A30: J33.5, U29.20
A31: GPIO18PU5.1, J33.6, U29.21
A32: J33.7, U29.17
A33: J33.8, U29.12
A34: J33.9, U29.10
A35: J33.10, U29.8
A36: J39.5, U34.20
A37: GPIO18PU6.1, J39.6, U34.21
A38: J39.7, U34.17
A39: J39.8, U34.12
A40: J39.9, U34.10
A41: J39.10, U34.8
A42: J45.5, U39.20
A43: GPIO18PU7.1, J45.6, U39.21
A44: J45.7, U39.17
A45: J45.8, U39.12
A46: J45.9, U39.10
A47: J45.10, U39.8
A48: J51.5, U44.20
A49: GPIO18PU8.1, J51.6, U44.21
A50: J51.7, U44.17
A51: J51.8, U44.12
A52: J51.9, U44.10
A53: J51.10, U44.8
A54: J57.5, U49.20
A55: GPIO18PU9.1, J57.6, U49.21
A56: J57.7, U49.17
A57: J57.8, U49.12
A58: J57.9, U49.10
A59: J57.10, U49.8
CC1: J5.A5, R12.2
CC2: J5.B5, R11.2
CC3: J10.B5, R29.2
CC4: J10.A5, R30.2
CC5: J16.B5, R45.2
CC6: J16.A5, R46.2
CC7: J22.B5, R61.2
CC8: J22.A5, R62.2
CC9: J28.B5, R77.2
CC10: J28.A5, R78.2
CC11: J34.B5, R93.2
CC12: J34.A5, R94.2
CC13: J40.B5, R109.2
CC14: J40.A5, R110.2
CC15: J46.B5, R125.2
CC16: J46.A5, R126.2
CC17: J52.B5, R141.2
CC18: J52.A5, R142.2
CC19: J58.B5, R157.2
CC20: J58.A5, R158.2
CHG: D1.C, U4.1
CHG1: D5.C, U6.1
CHG2: D8.C, U11.1
CHG3: D11.C, U16.1
CHG4: D14.C, U21.1
CHG5: D17.C, U26.1
CHG6: D20.C, U31.1
CHG7: D23.C, U36.1
CHG8: D26.C, U41.1
CHG9: D29.C, U46.1
CHIP_PU: C8.1, J4.1, J6.10, Q2.3, R10.1, S1.4, U1.41
CHIP_PU1: C20.1, J9.1, J11.10, Q4.3, R27.1, S3.4, U9.41
CHIP_PU2: C30.1, J15.1, J17.10, Q6.3, R43.1, S5.4, U14.41
CHIP_PU3: C40.1, J21.1, J23.10, Q8.3, R59.1, S7.4, U19.41
CHIP_PU4: C50.1, J27.1, J29.10, Q10.3, R75.1, S9.4, U24.41
CHIP_PU5: C60.1, J33.1, J35.10, Q12.3, R91.1, S11.4, U29.41
CHIP_PU6: C70.1, J39.1, J41.10, Q14.3, R107.1, S13.4, U34.41
CHIP_PU7: C80.1, J45.1, J47.10, Q16.3, R123.1, S15.4, U39.41
CHIP_PU8: C90.1, J51.1, J53.10, Q18.3, R139.1, S17.4, U44.41
CHIP_PU9: C100.1, J57.1, J59.10, Q20.3, R155.1, S19.4, U49.41
CIPO: J4.13, U1.31
CIPO1: J9.13, U9.31
CIPO2: J15.13, U14.31
CIPO3: J21.13, U19.31
CIPO4: J27.13, U24.31
CIPO5: J33.13, U29.31
CIPO6: J39.13, U34.31
CIPO7: J45.13, U39.31
CIPO8: J51.13, U44.31
CIPO9: J57.13, U49.31
COPI: J4.12, U1.29
COPI1: J9.12, U9.29
COPI2: J15.12, U14.29
COPI3: J21.12, U19.29
COPI4: J27.12, U24.29
COPI5: J33.12, U29.29
COPI6: J39.12, U34.29
COPI7: J45.12, U39.29
COPI8: J51.12, U44.29
COPI9: J57.12, U49.29
CP210X_D+: U2.3, U5.1
CP210X_D+1: U8.3, U10.1
CP210X_D+2: U13.3, U15.1
CP210X_D+3: U18.3, U20.1
CP210X_D+4: U23.3, U25.1
CP210X_D+5: U28.3, U30.1
CP210X_D+6: U33.3, U35.1
CP210X_D+7: U38.3, U40.1
CP210X_D+8: U43.3, U45.1
CP210X_D+9: U48.3, U50.1
CP210X_D-: U2.4, U5.7
CP210X_D-1: U8.4, U10.7
CP210X_D-2: U13.4, U15.7
CP210X_D-3: U18.4, U20.7
CP210X_D-4: U23.4, U25.7
CP210X_D-5: U28.4, U30.7
CP210X_D-6: U33.4, U35.7
CP210X_D-7: U38.4, U40.7
CP210X_D-8: U43.4, U45.7
CP210X_D-9: U48.4, U50.7
DTR: Q2.1, R17.1, U2.23
DTR1: Q4.1, R20.1, U8.23
DTR2: Q6.1, R36.1, U13.23
DTR3: Q8.1, R52.1, U18.23
DTR4: Q10.1, R68.1, U23.23
DTR5: Q12.1, R84.1, U28.23
DTR6: Q14.1, R100.1, U33.23
DTR7: Q16.1, R116.1, U38.23
DTR8: Q18.1, R132.1, U43.23
DTR9: Q20.1, R148.1, U48.23
EN: J2.2, R8.2, U3.3
EN1: J8.2, R24.2, U7.3
EN2: J14.2, R40.2, U12.3
EN3: J20.2, R56.2, U17.3
EN4: J26.2, R72.2, U22.3
EN5: J32.2, R88.2, U27.3
EN6: J38.2, R104.2, U32.3
EN7: J44.2, R120.2, U37.3
EN8: J50.2, R136.2, U42.3
EN9: J56.2, R152.2, U47.3
ESP32_D+: U1.23, U5.2
ESP32_D+1: U9.23, U10.2
ESP32_D+2: U14.23, U15.2
ESP32_D+3: U19.23, U20.2
ESP32_D+4: U24.23, U25.2
ESP32_D+5: U29.23, U30.2
ESP32_D+6: U34.23, U35.2
ESP32_D+7: U39.23, U40.2
ESP32_D+8: U44.23, U45.2
ESP32_D+9: U49.23, U50.2
ESP32_D-: U1.22, U5.6
ESP32_D-1: U9.22, U10.6
ESP32_D-2: U14.22, U15.6
ESP32_D-3: U19.22, U20.6
ESP32_D-4: U24.22, U25.6
ESP32_D-5: U29.22, U30.6
ESP32_D-6: U34.22, U35.6
ESP32_D-7: U39.22, U40.6
ESP32_D-8: U44.22, U45.6
ESP32_D-9: U49.22, U50.6
GND: C1.2, C2.2, C3.2, C4.1, C5.1, C6.2, C7.2, C8.2, C10.2, C19.2, D3.C, J3.1, J4.4, J5.GND, J5.GND2, J6.3, J6.5, J6.7, J6.9, JP2.1, R6.1, R7.1, R9.1, R11.1, R12.1, R13.2, S1.1, S2.1, U1.1, U1.26, U1.42, U1.GNDEP0, U1.GNDEP1, U1.GNDEP2, U1.GNDEP3, U1.GNDEP4, U1.GNDEP5, U1.GNDEP6, U1.GNDEP7, U1.GNDEP8, U2.2, U2.PAD, U3.2, U4.2, U5.4, U5.8, USB.3
GND1: C9.2, C11.2, C12.2, C13.2, C14.2, C15.2, C16.2, C17.1, C18.1, C20.2, D6.C, J1.1, J9.4, J10.GND, J10.GND2, J11.3, J11.5, J11.7, J11.9, JP1.1, R15.1, R19.1, R26.1, R29.1, R30.1, R31.2, S3.1, S4.1, U6.2, U7.2, U8.2, U8.PAD, U9.1, U9.26, U9.42, U9.GNDEP0, U9.GNDEP1, U9.GNDEP2, U9.GNDEP3, U9.GNDEP4, U9.GNDEP5, U9.GNDEP6, U9.GNDEP7, U9.GNDEP8, U10.4, U10.8, USB1.3
GND2: C21.2, C22.2, C23.2, C24.2, C25.2, C26.2, C27.2, C28.1, C29.1, C30.2, D9.C, J13.1, J15.4, J16.GND, J16.GND2, J17.3, J17.5, J17.7, J17.9, JP3.1, R33.1, R35.1, R42.1, R45.1, R46.1, R47.2, S5.1, S6.1, U11.2, U12.2, U13.2, U13.PAD, U14.1, U14.26, U14.42, U14.GNDEP0, U14.GNDEP1, U14.GNDEP2, U14.GNDEP3, U14.GNDEP4, U14.GNDEP5, U14.GNDEP6, U14.GNDEP7, U14.GNDEP8, U15.4, U15.8, USB2.3
GND3: C31.2, C32.2, C33.2, C34.2, C35.2, C36.2, C37.2, C38.1, C39.1, C40.2, D12.C, J19.1, J21.4, J22.GND, J22.GND2, J23.3, J23.5, J23.7, J23.9, JP4.1, R49.1, R51.1, R58.1, R61.1, R62.1, R63.2, S7.1, S8.1, U16.2, U17.2, U18.2, U18.PAD, U19.1, U19.26, U19.42, U19.GNDEP0, U19.GNDEP1, U19.GNDEP2, U19.GNDEP3, U19.GNDEP4, U19.GNDEP5, U19.GNDEP6, U19.GNDEP7, U19.GNDEP8, U20.4, U20.8, USB3.3
GND4: C41.2, C42.2, C43.2, C44.2, C45.2, C46.2, C47.2, C48.1, C49.1, C50.2, D15.C, J25.1, J27.4, J28.GND, J28.GND2, J29.3, J29.5, J29.7, J29.9, JP5.1, R65.1, R67.1, R74.1, R77.1, R78.1, R79.2, S9.1, S10.1, U21.2, U22.2, U23.2, U23.PAD, U24.1, U24.26, U24.42, U24.GNDEP0, U24.GNDEP1, U24.GNDEP2, U24.GNDEP3, U24.GNDEP4, U24.GNDEP5, U24.GNDEP6, U24.GNDEP7, U24.GNDEP8, U25.4, U25.8, USB4.3
GND5: C51.2, C52.2, C53.2, C54.2, C55.2, C56.2, C57.2, C58.1, C59.1, C60.2, D18.C, J31.1, J33.4, J34.GND, J34.GND2, J35.3, J35.5, J35.7, J35.9, JP6.1, R81.1, R83.1, R90.1, R93.1, R94.1, R95.2, S11.1, S12.1, U26.2, U27.2, U28.2, U28.PAD, U29.1, U29.26, U29.42, U29.GNDEP0, U29.GNDEP1, U29.GNDEP2, U29.GNDEP3, U29.GNDEP4, U29.GNDEP5, U29.GNDEP6, U29.GNDEP7, U29.GNDEP8, U30.4, U30.8, USB5.3
GND6: C61.2, C62.2, C63.2, C64.2, C65.2, C66.2, C67.2, C68.1, C69.1, C70.2, D21.C, J37.1, J39.4, J40.GND, J40.GND2, J41.3, J41.5, J41.7, J41.9, JP7.1, R97.1, R99.1, R106.1, R109.1, R110.1, R111.2, S13.1, S14.1, U31.2, U32.2, U33.2, U33.PAD, U34.1, U34.26, U34.42, U34.GNDEP0, U34.GNDEP1, U34.GNDEP2, U34.GNDEP3, U34.GNDEP4, U34.GNDEP5, U34.GNDEP6, U34.GNDEP7, U34.GNDEP8, U35.4, U35.8, USB6.3
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

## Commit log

2020-12-01 power routing looking almost there
    [ESP32-S2_Thing_Plus.brd, ESP32-S2_Thing_Plus.sch]
2020-12-02 added charge current jumper options and did a bunch of routing
    [ESP32-S2_Thing_Plus.brd, ESP32-S2_Thing_Plus.sch]
2020-12-04 Moved to smaller/newer 32.768kHz crystal
    [ESP32-S2_Thing_Plus.brd, ESP32-S2_Thing_Plus.sch]
2020-12-04 moving vreg in progress
    [ESP32-S2_Thing_Plus.brd]
2020-12-07 All IO (except "extra SMD IO") routed
    [ESP32-S2_Thing_Plus.brd, ESP32-S2_Thing_Plus.sch]
2020-12-07 routing "done"
    [ESP32-S2_Thing_Plus.brd, ESP32-S2_Thing_Plus.sch]
2020-12-08 DRC errors - some little nudging
    [ESP32-S2_Thing_Plus.brd, ESP32-S2_Thing_Plus.sch]
2020-12-09 schematic cleanup and added recommended RC (cap to GND) on enable pin
    [ESP32-S2_Thing_Plus.brd, ESP32-S2_Thing_Plus.sch]
2020-12-09 "0" boot test point moved to 50 mil grid
    [ESP32-S2_Thing_Plus.brd]
2020-12-09 added JTAG test points
    [ESP32-S2_Thing_Plus.brd, ESP32-S2_Thing_Plus.sch]
2020-12-09 trestrict on cp210x and ground trace connection from outer pad to EPAD
    [ESP32-S2_Thing_Plus.brd]
2020-12-09 Measures updated
    [ESP32-S2_Thing_Plus.brd]
2020-12-09 nudging vias to avoid silk
    [ESP32-S2_Thing_Plus.brd]
2020-12-10 prod_ids for module and usb switch ic
    [ESP32-S2_Thing_Plus.brd, ESP32-S2_Thing_Plus.sch]
2020-12-11 corrected extra IO sch note, moved "0" button to align with reset.
    [ESP32-S2_Thing_Plus.brd, ESP32-S2_Thing_Plus.sch]
2020-12-11 Group design review changes - USB switch to jumper and much more!
    -Moved USB selection switch to a 3-way jumper on the bottom.
    -Increased Battery + and - label text size
    -switched 5.1K resistors to 0402 package
    -Moved Charge LED away from standoff
    -More GND vias under CP210X
    -More GND vias near GND pad on JST batt input
    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
    [ESP32-S2_Thing_Plus.brd, ESP32-S2_Thing_Plus.sch]
2020-12-14 Final changes from groupd proto review (library work)
    -Added tNames and tValues to TC7 USB switch IC.
    -repositioned tNames and tValues on CP210X footprint.
    [ESP32-S2_Thing_Plus.brd, ESP32-S2_Thing_Plus.sch]
2020-12-14 Moved to new DRU, then moved some stuff for better gnd flow
    -note, manually kept gnd pour poly isolates at 7/10/10/7, to avoid exposing mask on square pad cornder masks.
    [ESP32-S2_Thing_Plus.brd]
2020-12-14 eng run checklist
    -one proportional font in sch fixed.
    -updated auto-reset paragraph in sch to reflect S2 strapping pins
    -updated USB selection jumper paragraph to more clearly show options and default.
    -removed S2 Module dimensions from footprint (forgot about them while doing the library work early on)
    -added more dimensions for header rows
    [ESP32-S2_Thing_Plus.brd, ESP32-S2_Thing_Plus.sch]
2020-12-15 DRU settings: mask openings to 2.5mil
    [ESP32-S2_Thing_Plus.brd]
2020-12-15 Added measures for JTAG header
    -also created dimensional drawings in PDF/PNG
    [ESP32-S2_Thing_Plus.brd]
2020-12-15 v01 proto gerbers
2021-02-15 v10
    -switched to normally open jumper on GPIO18. Testing showed this was unnecessary. (also updated jumper paragraph in schematic).
    -bumped version to v10 in both sch and brd.
    [ESP32-S2_Thing_Plus.brd, ESP32-S2_Thing_Plus.sch]
2021-02-15 datasheet page correction in sch note about GPIO18 jumper
    [ESP32-S2_Thing_Plus.sch]
2021-02-17 Reds Review changes - nudged test points
    -Test points were too close to bottom SMD header pads. Moved them slightly away.
    -Fixed one DRC angle error on a trace off of jumper pad
    -Changes EN and RESET buzzard bottom labels to be POINTER END as input to board.
    [ESP32-S2_Thing_Plus.brd]
2021-02-18 Adjusted GPIO45 and 46 to be INPUT pointer style labels
    [ESP32-S2_Thing_Plus.brd]
2021-02-18 cleaning up measures
    [ESP32-S2_Thing_Plus.brd]
2021-02-25 Panel brd and gerbers for v10
    [ESP32-S2_Thing_Plus-Panel.brd]
2021-03-22 BOM switch - momentary switches to new nicer button (SWCH-15606)
    Note, I also updated production panel file, so this should help when using this to create recipe on pnp machine.
    [ESP32-S2_Thing_Plus-Panel.brd, ESP32-S2_Thing_Plus.brd, ESP32-S2_Thing_Plus.sch]
2021-04-05 Clarifying which datasheet to reference about GPIO18 pullup
    [ESP32-S2_Thing_Plus.sch]
2021-04-05 GPIO18 paragraph DS page correction (PG 20)
    [ESP32-S2_Thing_Plus.sch]

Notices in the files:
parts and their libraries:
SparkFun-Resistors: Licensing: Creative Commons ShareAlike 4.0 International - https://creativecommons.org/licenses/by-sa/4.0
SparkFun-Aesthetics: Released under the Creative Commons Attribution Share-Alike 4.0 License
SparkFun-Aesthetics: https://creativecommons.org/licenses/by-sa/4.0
